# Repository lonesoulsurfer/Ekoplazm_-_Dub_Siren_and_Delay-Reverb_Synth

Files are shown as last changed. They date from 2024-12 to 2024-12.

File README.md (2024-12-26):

# Ekoplazm - Dub Siren and Delay-Reverb Synth



This is my 3rd instalment in the ‘Little synths with BIG sound’ series.

This time around I’ve designed a 2 in 1 synth which I've called Ekoplazm! The first synth is a classic Dub Siren which I have paired up with a Delay and Reverb synth and includes feedback and a couple other tricks. You can play the Dub Siren through the Delay/Reverb section which gives it a rich and full sound or play other synths like my Proton & Elements synths through the Delay/Reverb section to add some tasty soundscapes to these synths.



Instructables step by step guide: https://www.instructables.com/Dub-Siren-DelayReverb-2-in-1-Synth-Little-Synths-W/

Youtube vid: https://www.youtube.com/watch?v=j3549u53hR0&source_ve_path=Mjg2NjY

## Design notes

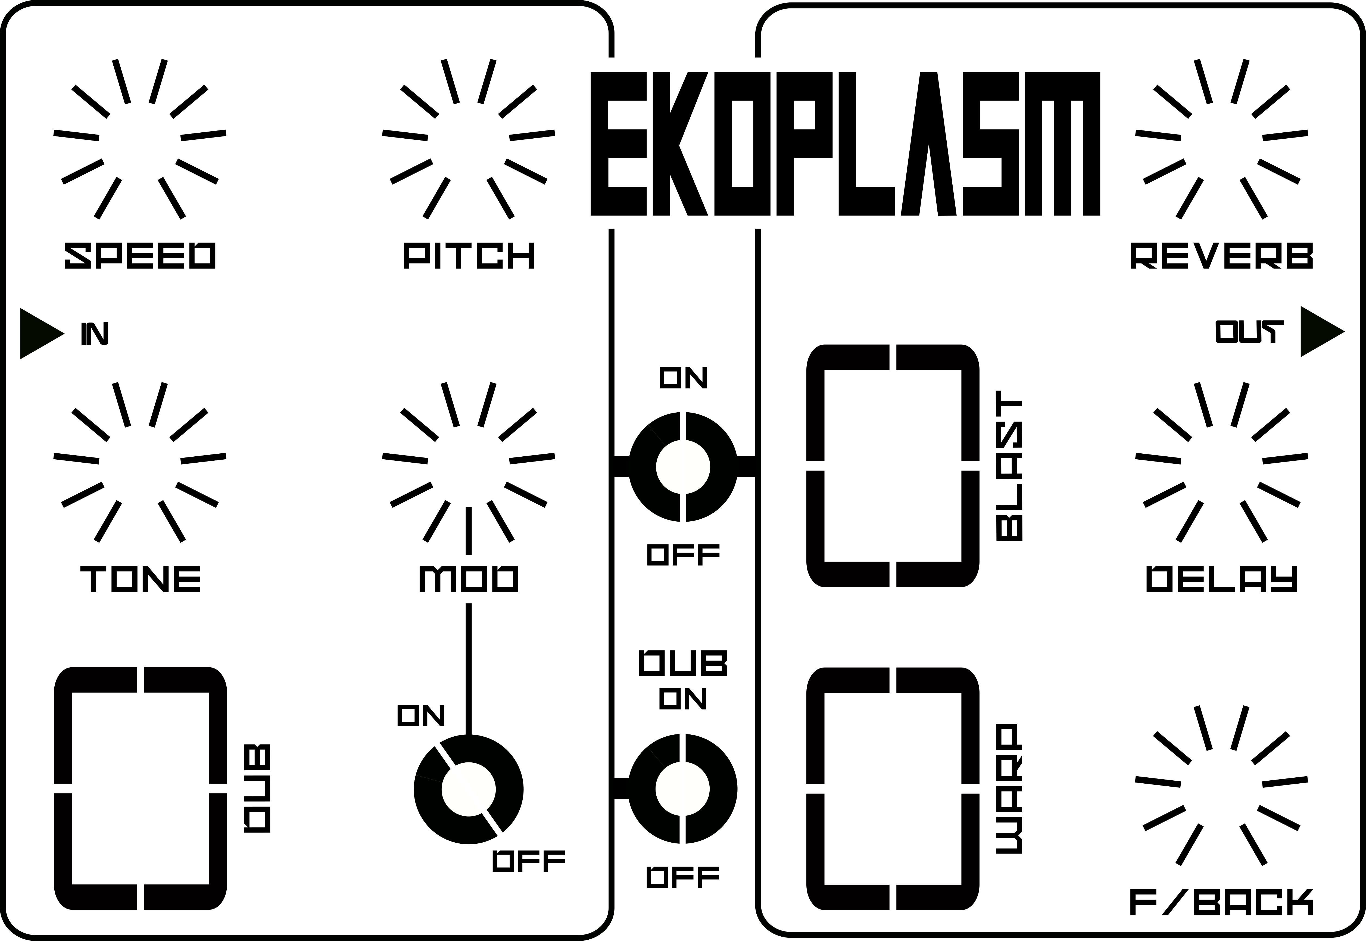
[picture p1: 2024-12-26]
Front Panel Design/Ekplazm Panel Inkscape.png

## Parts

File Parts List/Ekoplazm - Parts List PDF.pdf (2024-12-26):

Part | Type | Value | Qty | Part Name | Link | Image

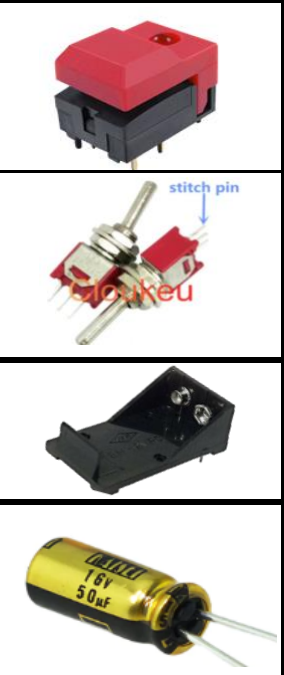
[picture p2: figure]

Switches | Momentary | | 3 | PB86-A1/A0 | Link (https://www.aliexpress.com/item/32969818198.html?src=google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)
| Toggle | | 3 | Through hole version | Link (https://www.aliexpress.com/item/1005001510219617.html)
Battery Holder | 9V | | 1 | BH9VPC | Link (https://www.ebay.com/sch/i.html?_from=R40&_nkw=9v+battery+holder+pcb+mount&_sacat=0)
Capacitor | Polarized | 4.7uf | 2 | | Link (https://www.aliexpress.com/item/1005004757060763.html?curPageLogUid=y0kXnp0fP7bz)
| | 47uf | 3
| | 470uf | 1
| | 10uf | 2
| | 100uf | 1
| Polyester | 100nf | 4 | | Link (https://www.aliexpress.com/item/1005001924935972.html?curPageLogUid=lzvFjF2pV8Pr)
| | 150nf | 1
| | 47nf | 1
| | 1nf | 1
| | 82nf | 2
| | 3.3nf | 1
| | 3.9nf | 1
| Ceramic | 560pf | 2 | | Link (https://www.aliexpress.com/w/wholesale-ceramic-capacitor-560pf.html?spm=a2g0o.detail.search.0)
Potentiometer | 9 mm vertical | 20K | 1 | | Link (https://www.aliexpress.com/w/wholesale-9mm-vertical-potentiometer.html)
| | 50K | 7
IC's | 555 | | 2 | | Link (https://www.aliexpress.com/w/wholesale-555-ic.html?spm=a2g0o.detail.search.0)
| 741 | op amp | 1 | | Link (https://www.aliexpress.com/w/wholesale-741.-ic.html?spm=a2g0o.productlist.search.0)
| PT2399 | | 1 | | Link (https://www.aliexpress.com/w/wholesale-pt2399-ic.html?spm=a2g0o.productlist.search.0)
Voltage regulator | 7805 | | 1 | | Link (https://www.aliexpress.com/w/wholesale-7805.html?spm=a2g0o.productlist.search.0)

Part | Type | Value | Qty | Part Name | Link | Image
3.5 mm Audio Jack Connector | | | 2 | PJ320A | Link (https://www.aliexpress.com/w/wholesale-PJ320A-3.5mm.html?spm=a2g0o.productlist.search.0)
LED | 3mm | | 1 | | Link (https://www.aliexpress.com/w/wholesale-3mm-led.html?spm=a2g0o.detail.search.0)
JST PH Series Connector | | | 1 | B2B-PH-K-S | Link (https://www.aliexpress.com/item/1005005491528446.html?curPageLogUid=hshYy7fL84uu)
Resistor | Metal Film | 10K | 6 | | Link (https://www.aliexpress.com/w/wholesale-metal-film-resistor.html?spm=a2g0o.productlist.search.0)
| | 560R | 2
| | 68K | 1
| | 15K | 3
| | 2.2K | 2
| | 5.6k | 1
| | 1k | 1
| | 100R | 3
| | 4.7K | 1
| | 18K | 1
| | 100K | 1
Transistor | 2N3904 | | 1 | | Link (https://www.aliexpress.com/w/wholesale-2N3904.html?spm=a2g0o.productlist.search.0)

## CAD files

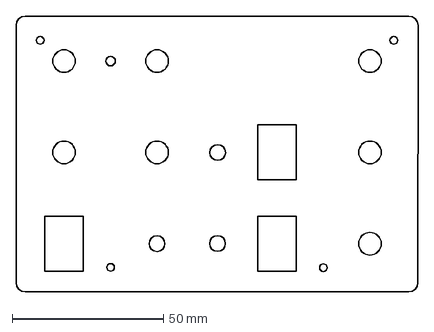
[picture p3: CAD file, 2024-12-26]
Front Panel Design/Ekoplazm - Kicad Files/Ekoplazm - Fusion.dxf
132.8 x 91.1 mm

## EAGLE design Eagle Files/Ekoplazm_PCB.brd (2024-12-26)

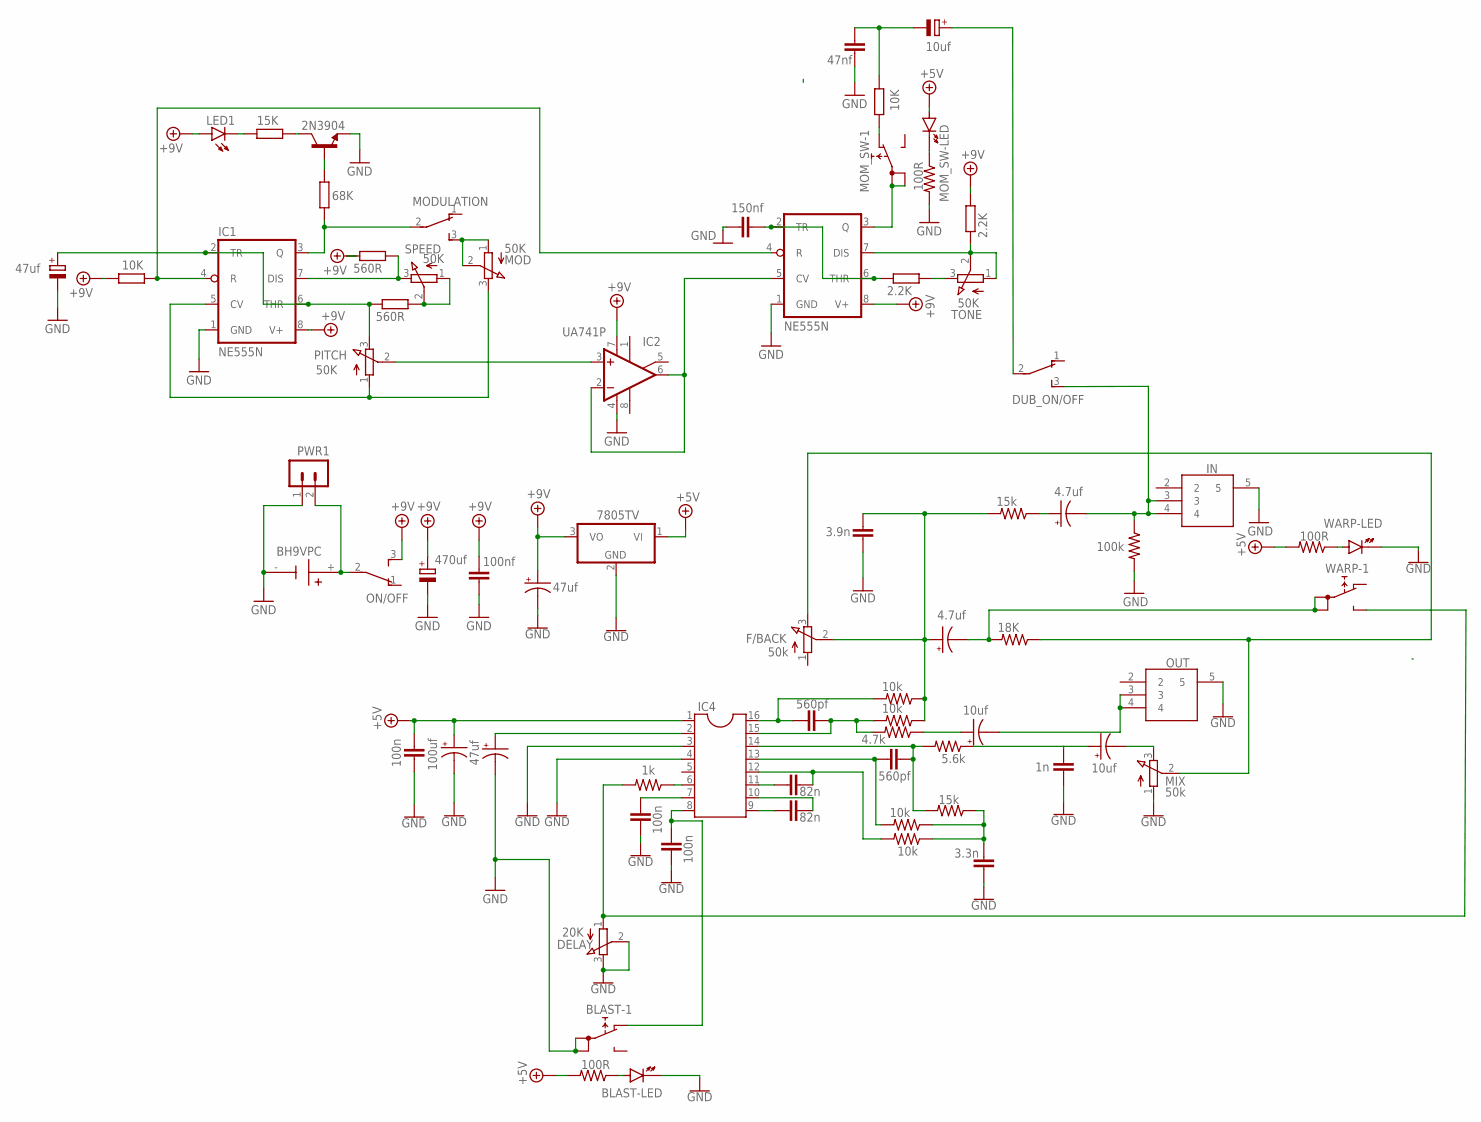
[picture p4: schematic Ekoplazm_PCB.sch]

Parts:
10K: 10K; 0207/10
BLAST: 5501-1LED
BT1: BH9VPC; BAT_BH9VPC
C1, C7, C14: 47uf; E2-5
C2: 470uf; E3,5-8
C3: 100nf; C050-024X044
C4: 150nf; C050-024X044
C5: 47nf; C050-024X044
C6, C18, C20: 10uf; E2-5
C8: 1n; C050-024X044
C9, C10, C11: 100n; C050-024X044
C12, C15: 82n; C050-024X044
C13: 100uf; E2-5
C16, C17: 560pf; C050-024X044
C19: 3.3n; C050-024X044
C21, C23: 4.7uf; E2-5
C22: 3.9n; C050-024X044
DELAY: 20K; EVUFXL
DUB_ON/OFF: TL36PO; TL3XPO
F/BACK: 50k; EVUFXL
IC1, IC3: NE555N; DIL08
IC2: UA741P; DIL08
IC4: DIL16
IC5: 7805TV; TO220V
IN: PJ-320A; PJ320A
LED1: LED3MM
MIX: 50k; EVUFXL
MOD: 50K; EVUF
MODULATION: TL36PO; TL3XPO
MOM_SW: 5501-1LED
ON/OFF: TL36PO; TL3XPO
OUT: PJ-320A; PJ320A
PITCH: 50K; EVUF
PWR1: B2B-PH-K-S
R1: 10K; 0207/10
R2, R7: 560R; 0207/10
R3: 68K; 0207/10
R4: 15K; 0207/10
R5, R6: 2.2K; 0207/10
R8, R12, R15, R17: 10k; 0207/10
R10: 5.6k; 0207/10
R11: 1k; 0207/10
R13, R19: 15k; 0207/10
R14, R21, R22: 100R; 0207/10
R16: 4.7k; 0207/10
R18: 18K; 0207/10
R20: 100k; 0207/10
SPEED: 50K; EVUF
T1: 2N3904; TO92
TONE: 50K; EVUF
WARP: 5501-1LED

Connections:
+5V: C9.1, C13.+, IC4.1, IC5.1 (VI), MOM_SW.+ (A), R14.2, R22.2
+9V: C2.+, C3.1, C14.+, IC1.8 (V+), IC2.7 (V+), IC3.8 (V+), IC5.3 (VO), LED1.A, ON/OFF.3 (S), R1.1, R6.2, R7.1
GND: BLAST.1A, BLAST.1B, BLAST.- (K), BT1.-, C1.-, C2.-, C3.2, C4.1, C5.1, C7.-, C8.2, C9.2, C10.2, C11.2, C13.-, C14.-, C19.1, C22.2, DELAY.2 (S), DELAY.3 (E), IC1.1 (GND), IC2.4 (V-), IC3.1 (GND), IC4.3, IC4.4, IC5.2 (GND), IN.5, MIX.1 (A), OUT.5, PWR1.1, R20.2, R21.2, T1.3 (E), WARP.- (K)
unnamed: C1.+, IC1.2 (TR), IC1.6 (THR), PITCH.3 (E), R2.1
unnamed: R2.2, SPEED.1 (A), SPEED.2 (S)
unnamed: IC1.7 (DIS), R7.2, SPEED.3 (E)
unnamed: IC1.5 (CV), MOD.3 (E), PITCH.1 (A)
unnamed: IC1.4 (R), IC3.4 (R), R1.2
unnamed: R3.2, T1.2 (B)
unnamed: R4.1, T1.1 (C)
unnamed: LED1.K (C), R4.2
unnamed: IC1.3 (Q), MODULATION.2, R3.1
unnamed: MOD.1 (A), MOD.2 (S), MODULATION.3 (S)
unnamed: BT1.+, ON/OFF.2, PWR1.2
unnamed: IC2.3 (+IN), PITCH.2 (S)
unnamed: IC2.2 (-IN), IC2.6 (OUT), IC3.5 (CV)
unnamed: C4.2, IC3.2 (TR), IC3.6 (THR), R5.1
unnamed: R5.2, TONE.3 (E)
unnamed: IC3.7 (DIS), R6.1, TONE.1 (A), TONE.2 (S)
unnamed: C7.+, IC4.2
unnamed: 10K.2, C5.2, C6.-
unnamed: C6.+, DUB_ON/OFF.2
unnamed: MOM_SW.- (K), R21.1
unnamed: IC4.6, R11.1
unnamed: C10.1, IC4.7
unnamed: C12.1, IC4.9
unnamed: C12.2, IC4.10
unnamed: C15.1, IC4.11
unnamed: C15.2, IC4.12, R8.2
unnamed: C19.2, R8.1, R12.1, R13.1
unnamed: C16.1, IC4.13, R12.2
unnamed: C16.2, IC4.14, R10.2, R13.2
unnamed: C8.1, C18.+, R10.1
unnamed: C20.+, R16.1
unnamed: C17.1, IC4.16, R17.2
unnamed: C17.2, IC4.15, R15.2, R16.2
unnamed: C21.+, C22.1, F/BACK.2 (S), R15.1, R17.1, R19.2
unnamed: C21.-, R18.2, WARP.1A, WARP.1B
unnamed: F/BACK.3 (E), MIX.2 (S), R18.1
unnamed: C23.+, R19.1
unnamed: C23.-, DUB_ON/OFF.3 (S), IN.3, IN.4, R20.1
unnamed: IC3.3 (Q), MOM_SW.1A, MOM_SW.1B
unnamed: DELAY.1 (A), R11.2, WARP.NO
unnamed: 10K.1, MOM_SW.NC
unnamed: BLAST.NC, C11.1, IC4.8
unnamed: BLAST.+ (A), R14.1
unnamed: C20.-, OUT.3, OUT.4
unnamed: C18.-, MIX.3 (E)
unnamed: R22.1, WARP.+ (A)

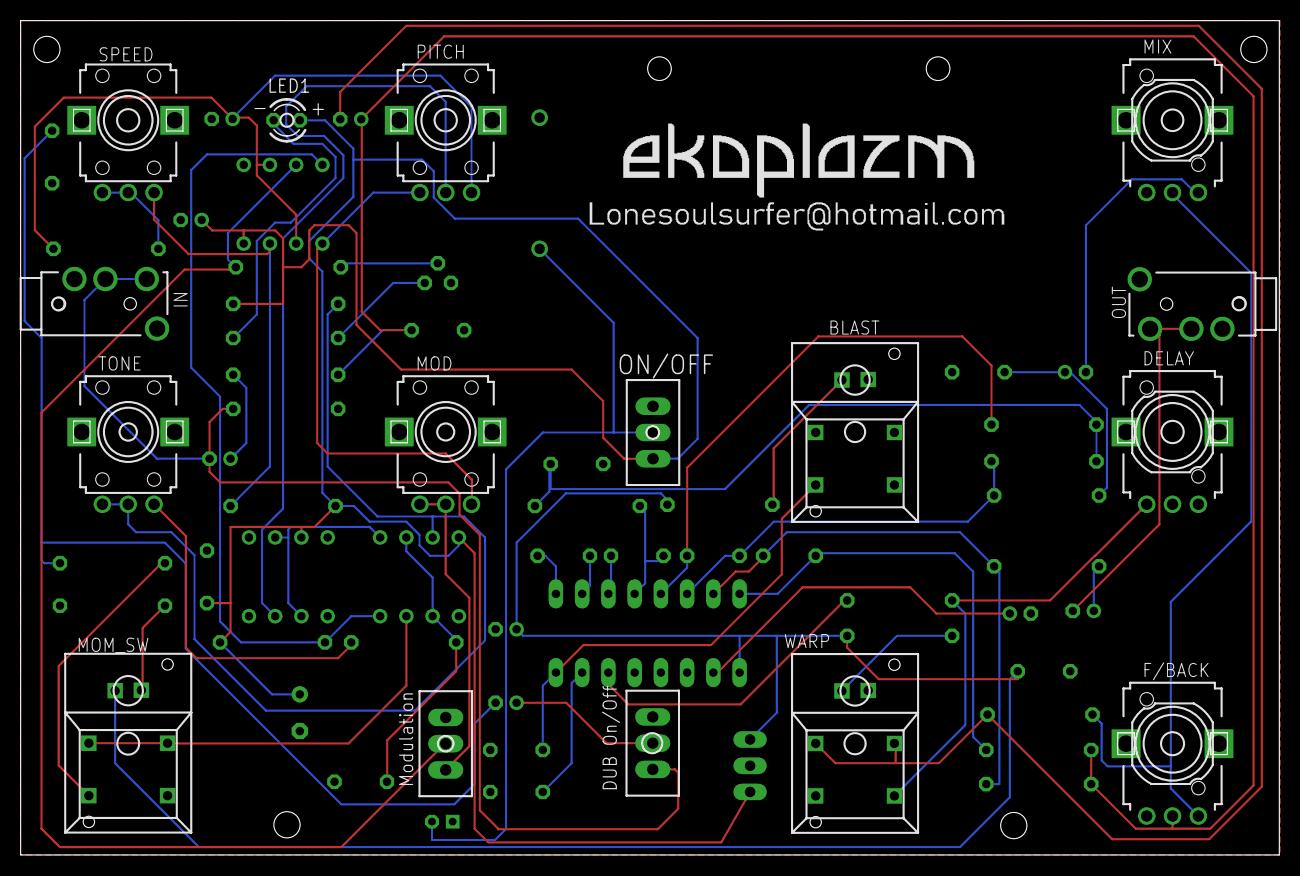
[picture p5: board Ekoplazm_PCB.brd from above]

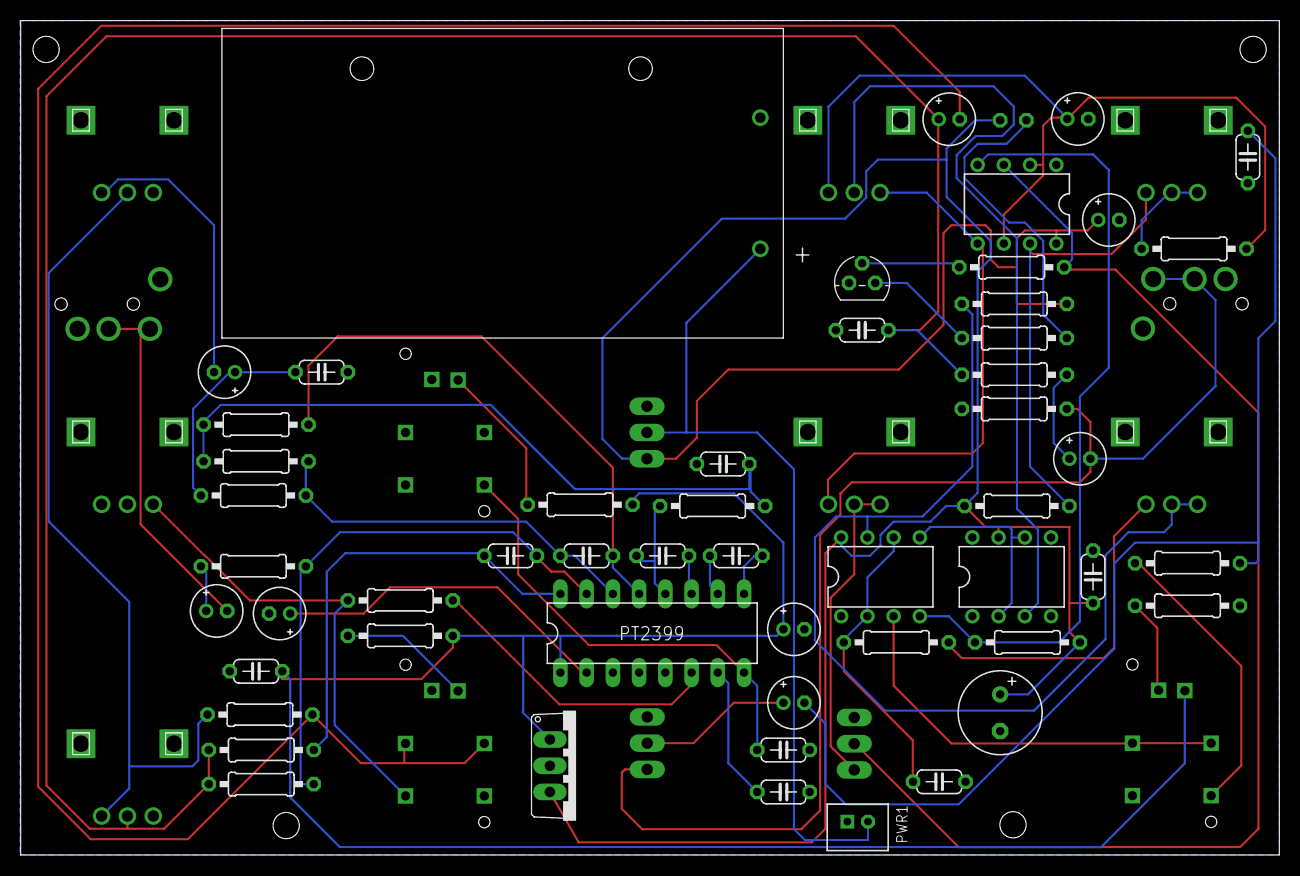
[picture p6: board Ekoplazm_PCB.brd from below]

Board: 2 copper layers, 121.8 x 80.8 mm, 69 parts (53 on the bottom side), 49 nets.

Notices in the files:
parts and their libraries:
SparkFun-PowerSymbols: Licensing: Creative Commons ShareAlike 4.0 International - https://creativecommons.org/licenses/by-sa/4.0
